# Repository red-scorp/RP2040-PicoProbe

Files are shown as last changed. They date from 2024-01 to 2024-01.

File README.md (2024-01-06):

```
 ______ ______ ______ ______ _____  ______
|   __ \   __ \__    |      |  |  ||      |
|      <    __/    __|  --  |__    |  --  |
|___|__|___|  |______|______|  |__||______|
 ______ __              ______              __
|   __ \__|.----.-----.|   __ \.----.-----.|  |--.-----.
|    __/  ||  __|  _  ||    __/|   _|  _  ||  _  |  -__|
|___|  |__||____|_____||___|   |__| |_____||_____|_____|
```

# RP2040-PicoProbe Project

The **RP2040-PicoProbe** project aims to create even smaller version of RP2040-DebugProbe.

## RP2040-PicoProbe Board

The **RP2040-PicoProbe** board is a 4-layer design intended to accommodate the popular Raspberry Pi RP2040 MCU with all required component to function identically to Raspberry Pi Debug Probe.

This board features target debug connector and PC host micro-USB connector.The board is pin-compatible with Raspberry Pi Debug Probe and can be used with the same picoprobe SW.

Preview:

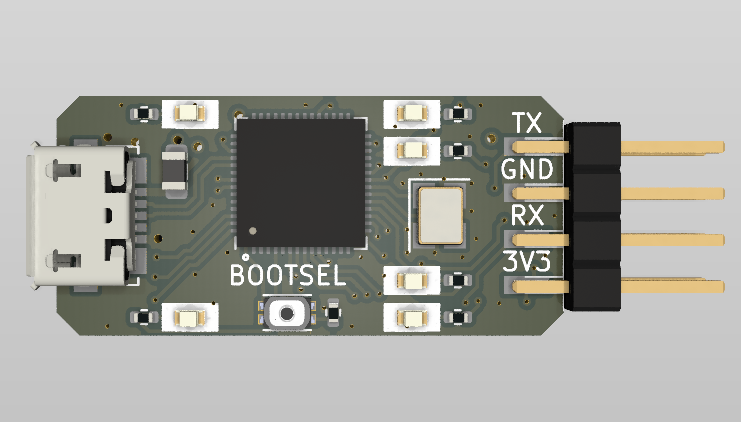
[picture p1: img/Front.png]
RP2040-PicoProbe Front preview

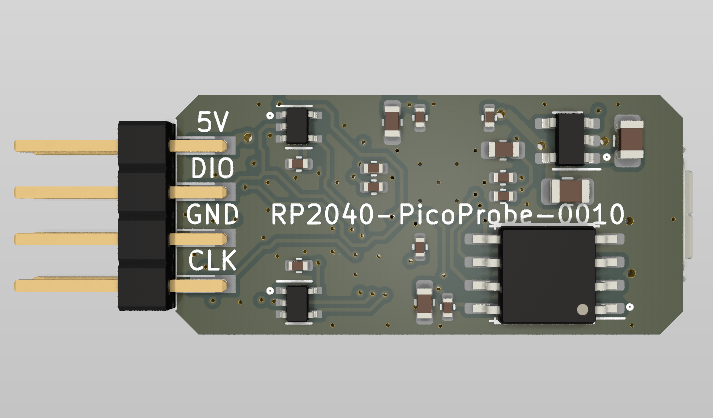
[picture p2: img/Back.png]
RP2040-PicoProbe Back preview

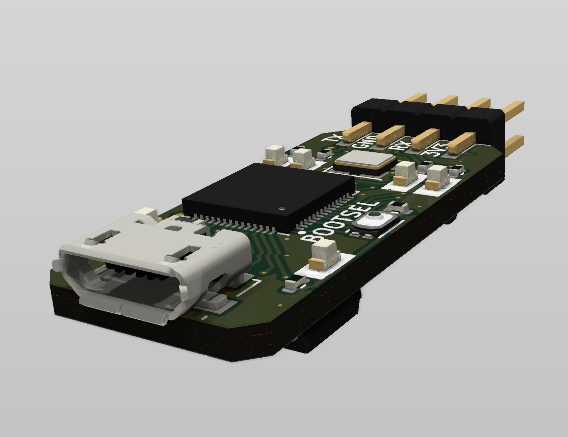
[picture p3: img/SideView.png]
RP2040-PicoProbe Side View preview


You can view the [Schematics in PDF format](doc/RP2040-PicoProbe.pdf) for detailed information.

STEP 3D file is available [with pins](doc/RP2040-PicoProbe.step).

Features:

- Very small form-factor of about 28x13mm, about 37x13mm with pins.
- Raspberry Pi RP2040 MCU as a heart of the board.
- 2x8 2.54mm SWD/UART/Power connector for programming and debugging.
- Micro USB connector for power and communication.
- Several LEDs to indicate power and status.
- Castellated holes connector for main MCU debugging.
- BOOTSEL button to enter the bootloader mode for flashing new picoprobe SW.
- Pin-compatible with Raspberry Pi Debug Probe.
- Double-sided assembly.

CAM files, as well as the BOM and CPL files for JLCPCB, are available.

## Version History

### v1.0b1

v1.0b1 board preview

Initial release for testing purposes.

## Links

- [Raspberry Pi RP2040 information page](https://www.raspberrypi.com/documentation/microcontrollers/rp2040.html).
- [Raspberry Pi Debug Probe information page](https://www.raspberrypi.com/documentation/microcontrollers/debug-probe.html).
- [Picoprobe SW for the board](https://github.com/raspberrypi/picoprobe).

## How to Help

Your contributions as code, resources, or finances are welcome! Please contact me directly via email at andriy.golovnya@gmail.com or through my [GitHub profile](https://github.com/red-scorp).

If you'd like to make a financial contribution, you can donate via [PayPal](http://paypal.me/redscorp) or [Ko-Fi](http://ko-fi.com/redscorp). Your support is greatly appreciated.

Thanks in advance!

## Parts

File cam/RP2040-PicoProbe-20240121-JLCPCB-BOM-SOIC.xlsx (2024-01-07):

Qty | Designator | Footprint | JLCPCB Part# | Designation
2 | D7,D4 | 0603 | C72038 | YELLOW
1 | FB2 | 0805 | C1015 | GZ2012D101TF
2 | D2,D5 | 0603 | C2286 | RED
1 | J5 | SMD | C2763165 | USB_B_Micro
1 | U2 | LQFN-56(7x7) | C2040 | RP2040
7 | R3,R7,R5,R1,R6,R4,R2 | 0402 | C11702 | 1k
1 | S1 | SMD,1.6x2.6mm | C913786 | 1TS026A-1800-0553-CT
2 | D1,D6 | 0603 | C72043 | GREEN
1 | Y1 | SMD3225-4P | C9002 | 12MHz
10 | C4,C11,C9,C17,C13,C18,C2,C6,C10,C8 | 0402 | C1525 | 100nF
3 | C5,C1,C16 | 0603 | C1604 | 2.2uF
2 | U3,U6 | SC-70-5 | C2652100 | 74AUP1T17
2 | C14,C15 | 0805 | C15850 | 10uF
1 | U1 | SOIC-8-208mil | C97521 | W25Q128JVS
1 | U5 | SOT-23-5 | C37970 | MIC5205-3.3YM5

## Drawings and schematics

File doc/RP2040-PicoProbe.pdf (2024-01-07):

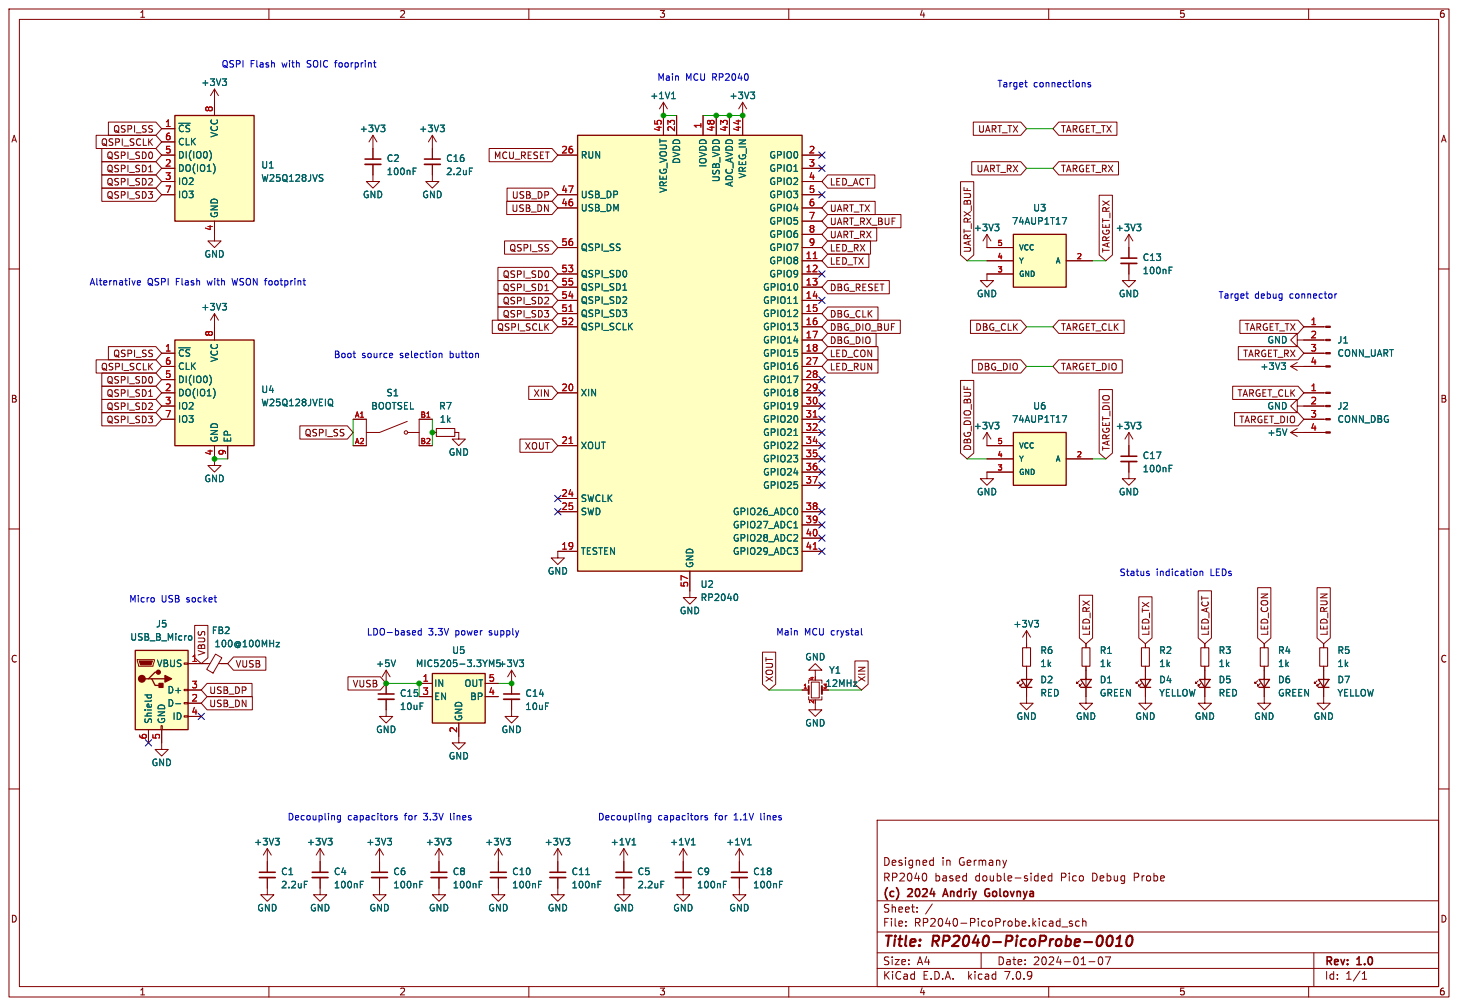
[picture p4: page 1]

QSPI Flash with SOIC foorprint

Target connections Main MCU crystal

1 GPIO8 11 GPIO9 12 GPIO10 13 GPIO11 14 GPIO12 15 GPIO13 16 GPIO14 17 GPIO15 18 TESTEN 19 GPIO0 2 XIN 20 XOUT 21 DVDD 23 SWCLK 24 SWD 25 RUN 26 GPIO16 27 GPIO17 28 GPIO18 29 GPIO1 3 GPIO19 30 GPIO20 31 GPIO21 32 GPIO22 34 GPIO23 35 GPIO24 36 GPIO25 37 GPIO26_ADC0 38 GPIO27_ADC1 39 GPIO2 4 GPIO28_ADC2 40 GPIO29_ADC3 41 ADC_AVDD 43 VREG_IN 44 VREG_VOUT 45 USB_DM 46 USB_DP 47 USB_VDD 48 GPIO3 5 QSPI_SD3 51 QSPI_SCLK 52 QSPI_SD0 53 QSPI_SD2 54 QSPI_SD1 55 QSPI_SS 56 GND 57 GPIO4 6 GPIO5 7 GPIO6 8 GPIO7 9 U2 RP2040 C6

1 GPIO8 11 GPIO9 12 GPIO10 13 GPIO11 14 GPIO12 15 GPIO13 16 GPIO14 17 GPIO15 18 TESTEN 19 GPIO0 2 XIN 20 XOUT 21 DVDD 23 SWCLK 24 SWD 25 RUN 26 GPIO16 27 GPIO17 28 GPIO18 29 GPIO1 3 GPIO19 30 GPIO20 31 GPIO21 32 GPIO22 34 GPIO23 35 GPIO24 36 GPIO25 37 GPIO26_ADC0 38 GPIO27_ADC1 39 GPIO2 4 GPIO28_ADC2 40 GPIO29_ADC3 41 ADC_AVDD 43 VREG_IN 44 VREG_VOUT 45 USB_DM 46 USB_DP 47 USB_VDD 48 GPIO3 5 QSPI_SD3 51 QSPI_SCLK 52 QSPI_SD0 53 QSPI_SD2 54 QSPI_SD1 55 QSPI_SS 56 GND 57 GPIO4 6 GPIO5 7 GPIO6 8 GPIO7 9 U3

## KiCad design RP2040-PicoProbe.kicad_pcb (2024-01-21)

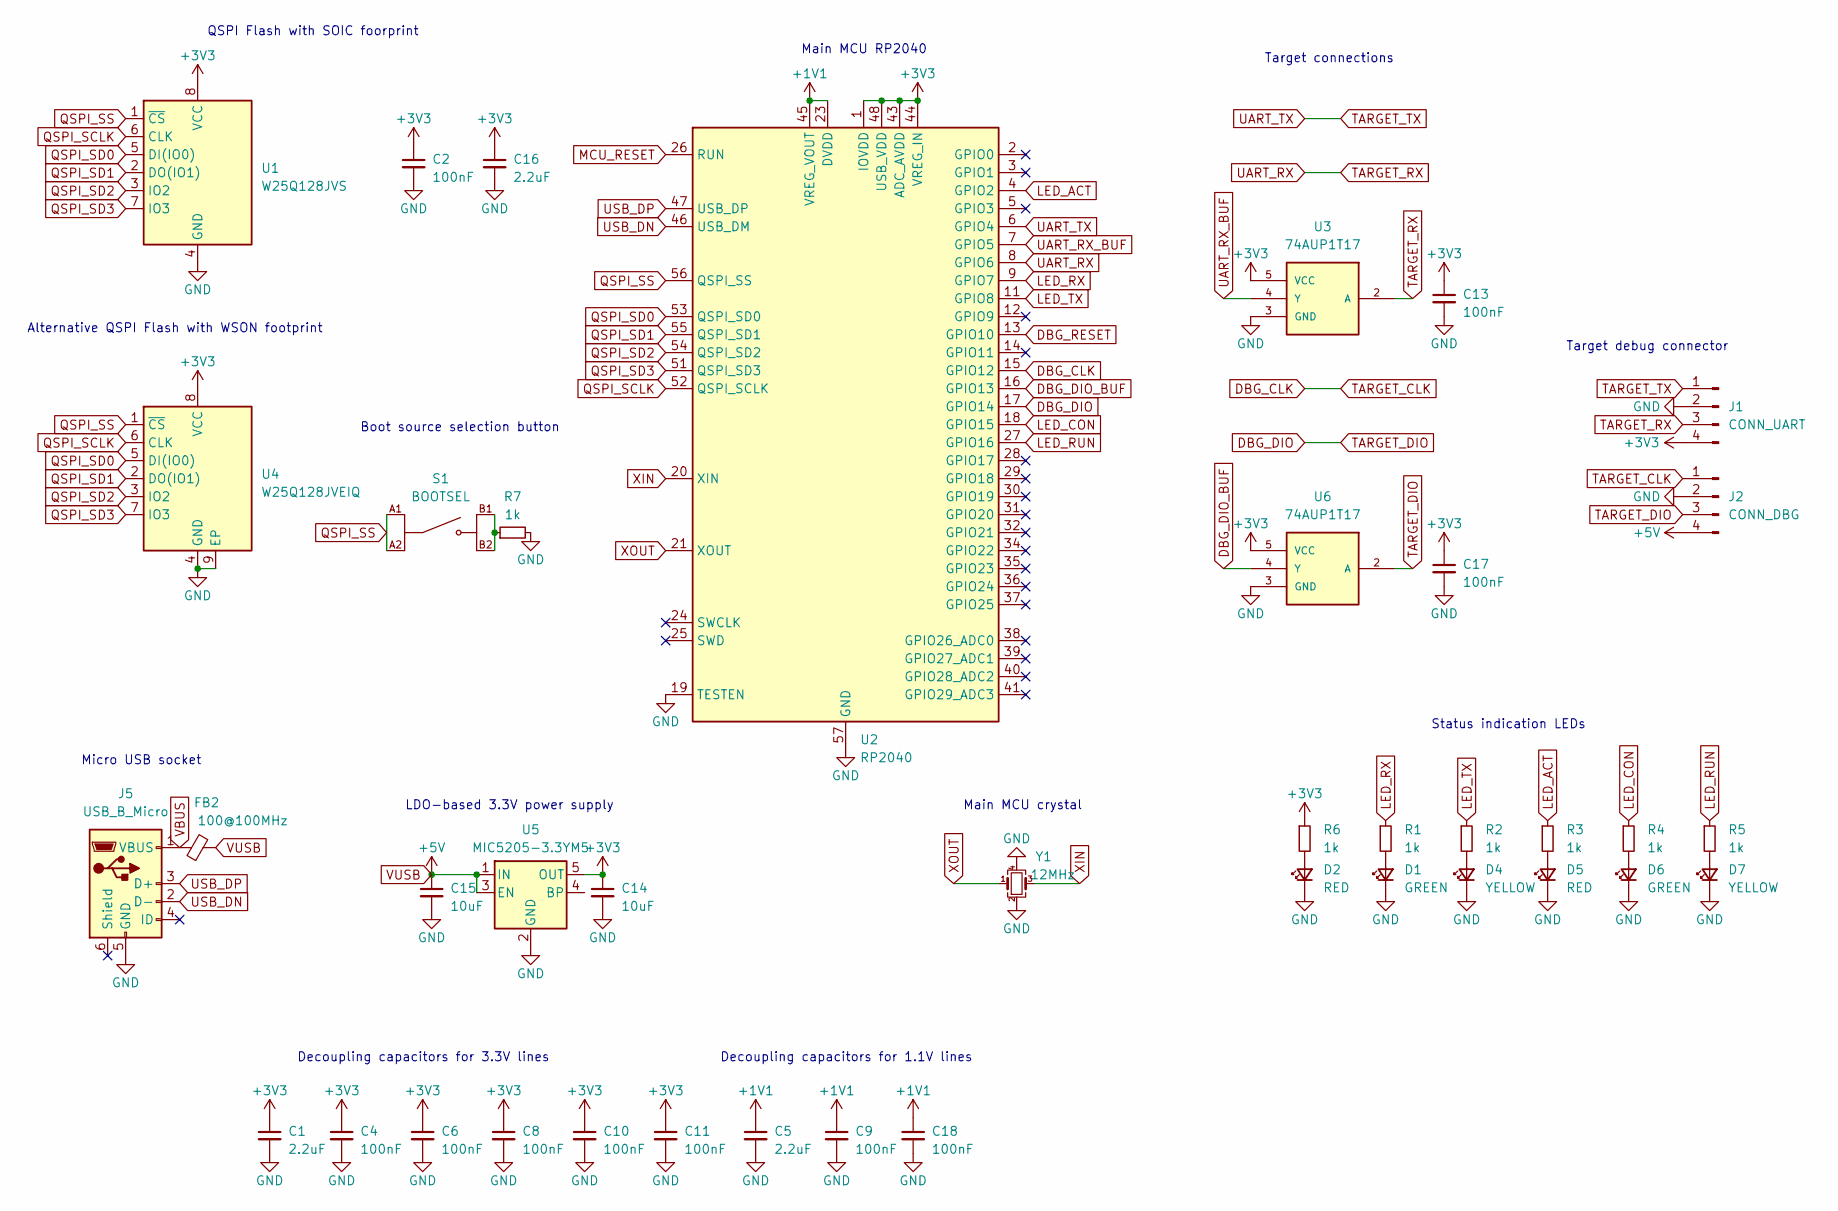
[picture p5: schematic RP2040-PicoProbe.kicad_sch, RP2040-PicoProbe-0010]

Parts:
C1, C5, C16: 2.2uF; C_0603_1608Metric
C2, C4, C6, C8, C9, C10, C11, C13, C17, C18: 100nF; C_0402_1005Metric
C14, C15: 10uF; C_0805_2012Metric
D1, D6: GREEN; LED_0603_1608Metric
D2, D5: RED; LED_0603_1608Metric
D4, D7: YELLOW; LED_0603_1608Metric
FB2: 100@100MHz; L_0805_2012Metric
J1: CONN_UART; Harwin_M20-89004xx_1x04_P2.54mm_Horizontal
J2: CONN_DBG; Harwin_M20-89004xx_1x04_P2.54mm_Horizontal
J5: USB_B_Micro; USB_Micro-B_Molex_47346-0001
R1, R2, R3, R4, R5, R6, R7: 1k; R_0402_1005Metric
S1: BOOTSEL; SW_EVPBB0AAB000; DIGI-KEY_PART_NUMBER P19888CT-ND
U1: W25Q128JVS; SOIC-8_5.23x5.23mm_P1.27mm
U2: RP2040; QFN-56-1EP_7x7mm_P0.4mm_EP3.2x3.2mm
U3, U6: 74AUP1T17; SOT-353_SC-70-5
U4: W25Q128JVEIQ; WSON-8-1EP_6x5mm_P1.27mm_EP3.4x4.3mm
U5: MIC5205-3.3YM5; SOT-23-5
Y1: 12MHz; Crystal_SMD_3225-4Pin_3.2x2.5mm

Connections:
+1V1: C5.1, C9.1, C18.1, U2.23 (DVDD), U2.45 (VREG_VOUT), U2.50 (DVDD)
+3V3: C1.1, C2.1, C4.1, C6.1, C8.1, C10.1, C11.1, C13.1, C14.1, C16.1, C17.1, J1.4, R6.1, U1.8 (VCC), U2.1 (IOVDD), U2.10 (IOVDD), U2.22 (IOVDD), U2.33 (IOVDD), U2.42 (IOVDD), U2.43 (ADC_AVDD), U2.44 (VREG_IN), U2.48 (USB_VDD), U2.49 (IOVDD), U3.5 (VCC), U4.8 (VCC), U5.5 (OUT), U6.5 (VCC)
DBG_CLK: J2.1, U2.15 (GPIO12)
DBG_DIO: J2.3, U2.17 (GPIO14), U6.2 (A)
DBG_DIO_BUF: U2.16 (GPIO13), U6.4 (Y)
DBG_RESET: U2.13 (GPIO10)
GND: C1.2, C2.2, C4.2, C5.2, C6.2, C8.2, C9.2, C10.2, C11.2, C13.2, C14.2, C15.2, C16.2, C17.2, C18.2, D1.1 (K), D2.1 (K), D4.1 (K), D5.1 (K), D6.1 (K), D7.1 (K), J1.2, J2.2, J5.5 (GND), R7.2, U1.4 (GND), U2.19 (TESTEN), U2.57 (GND), U3.3 (GND), U4.4 (GND), U4.9 (EP), U5.2 (GND), U6.3 (GND), Y1.2, Y1.4
LED_ACT: R3.1, U2.4 (GPIO2)
LED_CON: R4.1, U2.18 (GPIO15)
LED_RUN: R5.1, U2.27 (GPIO16)
LED_RX: R1.1, U2.9 (GPIO7)
LED_TX: R2.1, U2.11 (GPIO8)
MCU_RESET: U2.26 (RUN)
unnamed: D1.2 (A), R1.2
unnamed: D2.2 (A), R6.2
unnamed: D4.2 (A), R2.2
unnamed: D5.2 (A), R3.2
unnamed: D6.2 (A), R4.2
unnamed: D7.2 (A), R5.2
unnamed: R7.1, S1.B1, S1.B2
QSPI_SCLK: U1.6 (CLK), U2.52 (QSPI_SCLK), U4.6 (CLK)
QSPI_SD0: U1.5 (DI(IO0)), U2.53 (QSPI_SD0), U4.5 (DI(IO0))
QSPI_SD1: U1.2 (DO(IO1)), U2.55 (QSPI_SD1), U4.2 (DO(IO1))
QSPI_SD2: U1.3 (IO2), U2.54 (QSPI_SD2), U4.3 (IO2)
QSPI_SD3: U1.7 (IO3), U2.51 (QSPI_SD3), U4.7 (IO3)
QSPI_SS: S1.A1, S1.A2, U1.1 (~CS), U2.56 (QSPI_SS), U4.1 (~CS)
TARGET_RX: J1.3, U2.8 (GPIO6), U3.2 (A)
TARGET_TX: J1.1, U2.6 (GPIO4)
UART_RX_BUF: U2.7 (GPIO5), U3.4 (Y)
USB_DN: J5.2 (D-), U2.46 (USB_DM)
USB_DP: J5.3 (D+), U2.47 (USB_DP)
VBUS: FB2.1, J5.1 (VBUS)
VUSB: C15.1, FB2.2, J2.4, U5.1 (IN), U5.3 (EN)
XIN: U2.20 (XIN), Y1.3
XOUT: U2.21 (XOUT), Y1.1

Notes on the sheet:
Alternative QSPI Flash with WSON footprint
Main MCU RP2040
Status indication LEDs
Decoupling capacitors for 3.3V lines
Main MCU crystal
Decoupling capacitors for 1.1V lines
Target connections
Target debug connector
Micro USB socket
Boot source selection button
LDO-based 3.3V power supply
QSPI Flash with SOIC foorprint

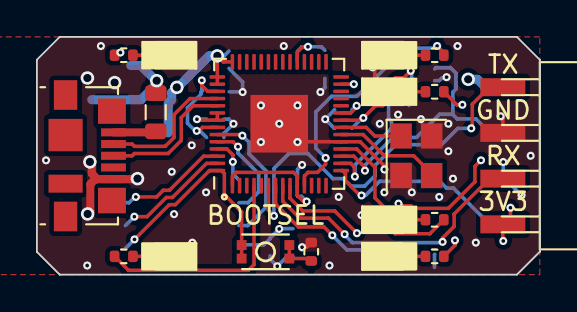
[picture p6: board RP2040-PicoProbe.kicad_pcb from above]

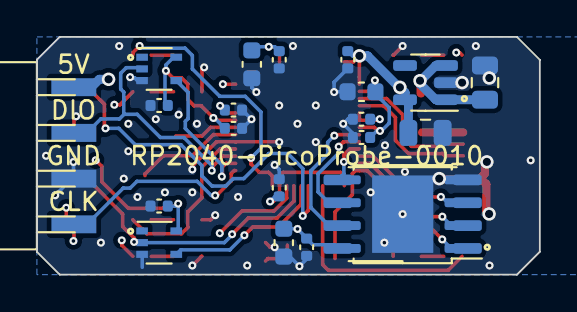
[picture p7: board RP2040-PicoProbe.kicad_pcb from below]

Board: 4 copper layers, 27.9 x 13.2 mm, 40 parts (21 on the bottom side), 33 nets.

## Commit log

2024-01-05 Used RP2040-MicroProbe files as base for the board.
    [RP2040-PicoProbe.kicad_pcb, RP2040-PicoProbe.kicad_sch]
2024-01-05 Renamed schematic and board title
    [RP2040-PicoProbe.kicad_pcb, RP2040-PicoProbe.kicad_sch]
2024-01-05 Removed host debug part. Moved secondary components to the back of the board.
    [RP2040-PicoProbe.kicad_pcb, RP2040-PicoProbe.kicad_sch]
2024-01-05 Roughly put components to their places
    [RP2040-PicoProbe.kicad_pcb, RP2040-PicoProbe.kicad_sch]
2024-01-06 Made the board smaller. Organized components to their expected locations.
    [RP2040-PicoProbe.kicad_pcb]
2024-01-06 Added traces between components
    [RP2040-PicoProbe.kicad_pcb]
2024-01-06 Moved stuff around
    [RP2040-PicoProbe.kicad_pcb]
2024-01-06 Generated PDF schematics
2024-01-07 Generated generic BOM and CPL files
    [RP2040-PicoProbe-20240107-JLCPCB-BOM.xlsx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]
2024-01-07 Generated BOM and CPL files
    [RP2040-PicoProbe-20240107-JLCPCB-BOM-SOIC.xlsx, RP2040-PicoProbe-20240107-JLCPCB-BOM-WSON.xlsx, RP2040-PicoProbe-20240107-JLCPCB-BOM.xlsx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]
2024-01-07 Some KiCad stuff
2024-01-07 Rotated few components
    [RP2040-PicoProbe-20240107-JLCPCB-CPL-SOIC.xlsx, RP2040-PicoProbe-20240107-JLCPCB-CPL-WSON.xlsx]
2024-01-13 Generated CAM files
    [RP2040-PicoProbe-20240107-JLCPCB-BOM-SOIC.xlsx, RP2040-PicoProbe-20240107-JLCPCB-BOM-WSON.xlsx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]

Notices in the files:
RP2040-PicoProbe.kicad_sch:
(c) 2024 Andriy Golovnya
